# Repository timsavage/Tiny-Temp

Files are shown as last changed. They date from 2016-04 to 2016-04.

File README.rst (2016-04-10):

########
TinyTemp
########

Had all the components laying about so this is a bit of a trial project for 
making my first PCB. 

Utilises a HP QDSP-6064 bubble display, a TMP34 temperature sensor, and an 
ATTiny85, will draw very little current for a longer life.

Hardware
========

The bubble displays can be hard to come by but they do pop up on Ebay from 
time to time.

Display is driven by a pair of 74HC595 IC's, one to control segments the other 
to switch transistors to pull Cathodes to ground. As the 74HC595 can be daisy
chained on 3 pins are required to drive the display. The TMP36 uses 1 ADC 
leaving one pin free.

Note that in the schematic the 3.3 Volt regulator used is the LD33V the pin
layout differs from the 78XX series in with:
 - Pin 1: GRN
 - Pin 2: OUT
 - Pin 3: IN

The schematic uses a 78XX series symbol.

The ICSP header is optional and only really in place for convenience.

BOM
---

 - 1x HP QDSP-6064 - 7 Segment "Bubble" display
 - 1x	ATTiny 85
 - 1x	TMP34 - Temperature sensor
 - 1x LD33V - 3.3V voltage regulator
 - 2x	74HC595 - Shift register
 - 4x	2N3904 - NPN transistor
 - 5x	10k ohm resistor
 - 4x	330 ohm resistor
 - 2x	0.1uF MLC cap

Software
========

Use the install target to build, upload, and set correct fuses for an ATTiny85
using a USBTiny programmer. These settings can be tweaked in the Makefile.

All pins, voltage levels (defaults to 3.3V) can be configured in *defines.h*.

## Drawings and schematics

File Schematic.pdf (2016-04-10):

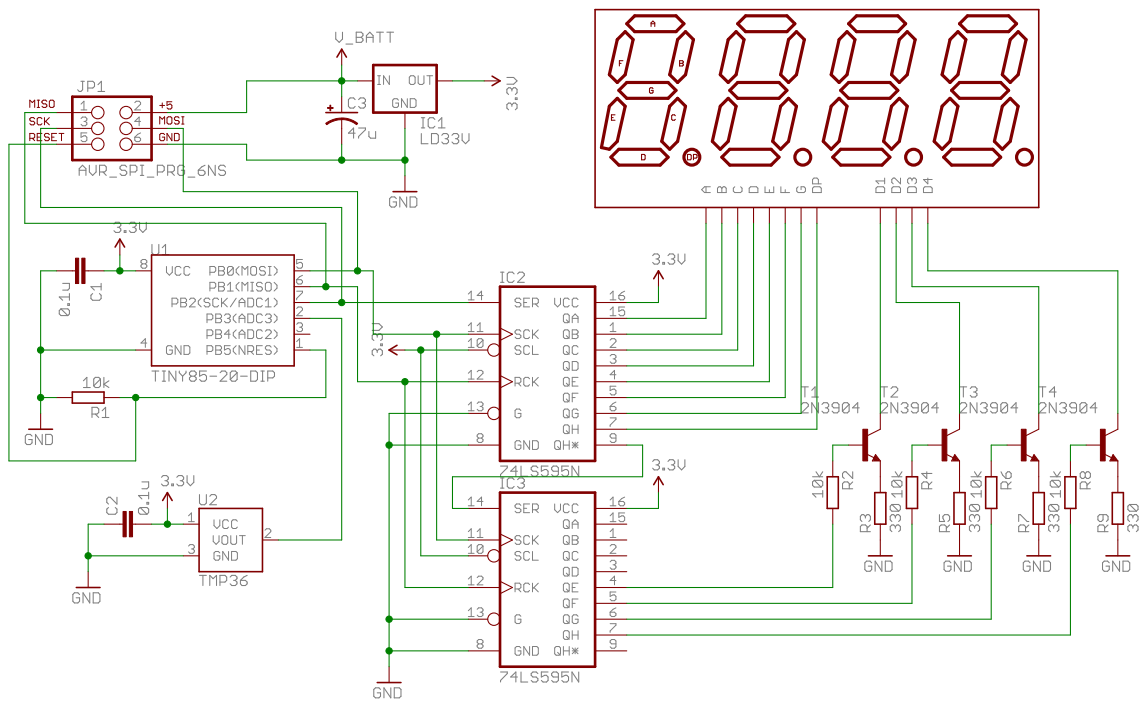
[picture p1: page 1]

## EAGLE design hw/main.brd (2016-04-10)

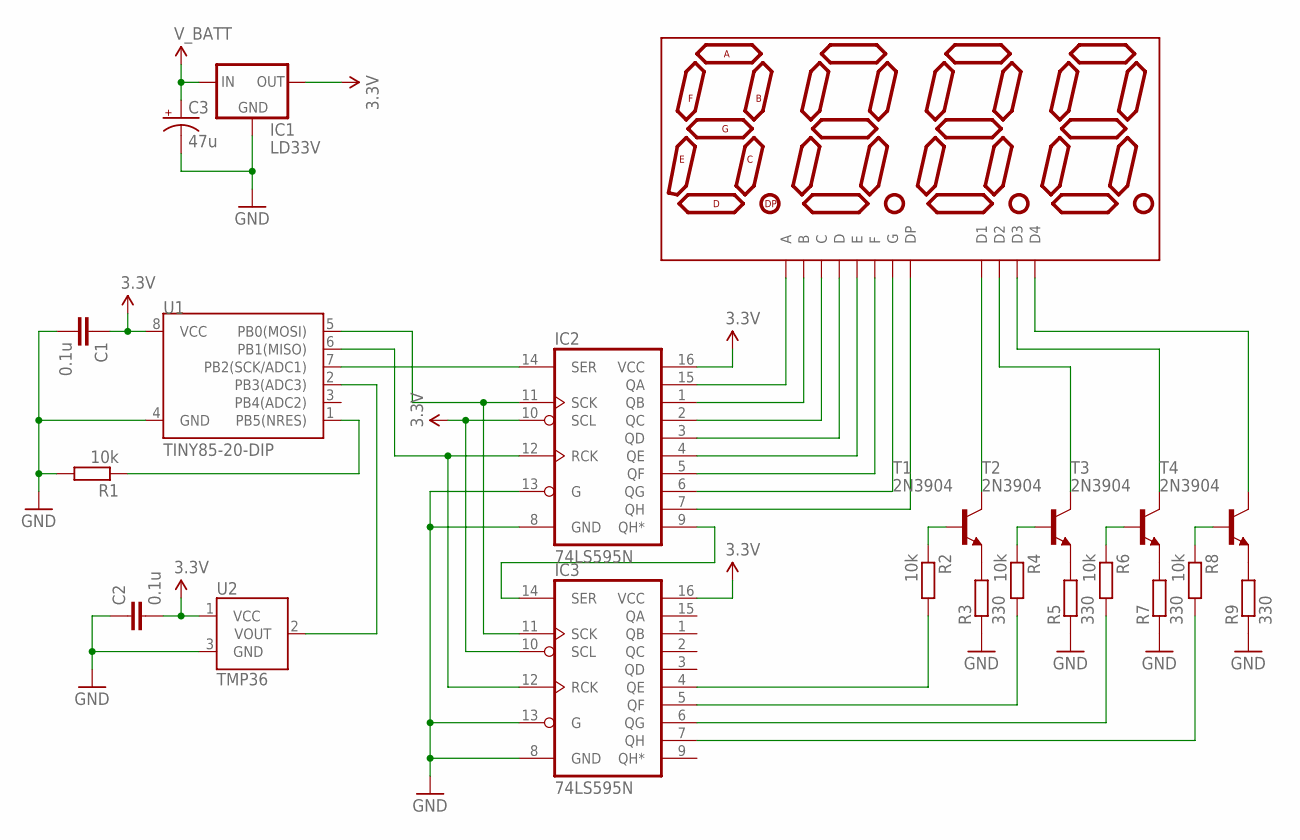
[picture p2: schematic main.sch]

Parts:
C1, C2: 0.1u; C025-025X050
C3: 47u; CPOL-RADIAL-10UF-25V
DISP1: 7-SEGMENT-4DIGIT-COUNTER-HP-BUBBLE; DIL12
IC1: LD33V; 78XXL
IC2, IC3: 74LS595N; DIL16
R1: 10k; 0204/7
R2, R4, R6, R8: 10k; 0204V
R3, R5, R7, R9: 330; 0204V
T1, T2, T3, T4: 2N3904; TO92
U1: TINY85-20-DIP; DIP08
U2: TMP36; TO-92

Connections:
GND: C1.2, C2.1, C3.2 (-), IC1.GND, IC2.8 (GND), IC2.13 (G), IC3.8 (GND), IC3.13 (G), R1.2, R3.1, R5.1, R7.1, R9.1, U1.4 (GND), U2.3 (GND); also elsewhere on the board
unnamed: DISP1.12 (A), IC2.15 (QA)
unnamed: DISP1.11 (B), IC2.1 (QB)
unnamed: DISP1.3 (C), IC2.2 (QC)
unnamed: DISP1.8 (D), IC2.3 (QD)
unnamed: DISP1.2 (E), IC2.4 (QE)
unnamed: DISP1.9 (F), IC2.5 (QF)
unnamed: DISP1.7 (G), IC2.6 (QG)
unnamed: DISP1.5 (DP), IC2.7 (QH)
unnamed: IC2.9 (QH*), IC3.14 (SER)
unnamed 10: IC2.11 (SCK), IC3.11 (SCK), U1.5 (PB0(MOSI)); also elsewhere on the board
unnamed 11: IC2.12 (RCK), IC3.12 (RCK), U1.6 (PB1(MISO)); also elsewhere on the board
unnamed: R3.2, T1.3 (E)
unnamed: R5.2, T2.3 (E)
unnamed: R9.2, T4.3 (E)
unnamed: R7.2, T3.3 (E)
unnamed: IC3.7 (QH), R8.2
unnamed: IC3.6 (QG), R6.2
unnamed: IC3.5 (QF), R4.2
unnamed: IC3.4 (QE), R2.2
unnamed: R2.1, T1.2 (B)
unnamed: R4.1, T2.2 (B)
unnamed: R6.1, T3.2 (B)
unnamed: R8.1, T4.2 (B)
unnamed: DISP1.1 (D1), T1.1 (C)
unnamed: DISP1.6 (D4), T4.1 (C)
unnamed: DISP1.4 (D3), T3.1 (C)
unnamed: DISP1.10 (D2), T2.1 (C)
unnamed: U1.2 (PB3(ADC3)), U2.2 (VOUT)
unnamed 29: R1.1, U1.1 (PB5(NRES)); also elsewhere on the board
unnamed 30: IC2.14 (SER), U1.7 (PB2(SCK/ADC1)); also elsewhere on the board
VCC: C1.1, C2.2, IC1.OUT, IC2.10 (SCL), IC2.16 (VCC), IC3.10 (SCL), IC3.16 (VCC), U1.8 (VCC), U2.1 (VCC)
V_BATT: C3.1 (+), IC1.IN; also elsewhere on the board

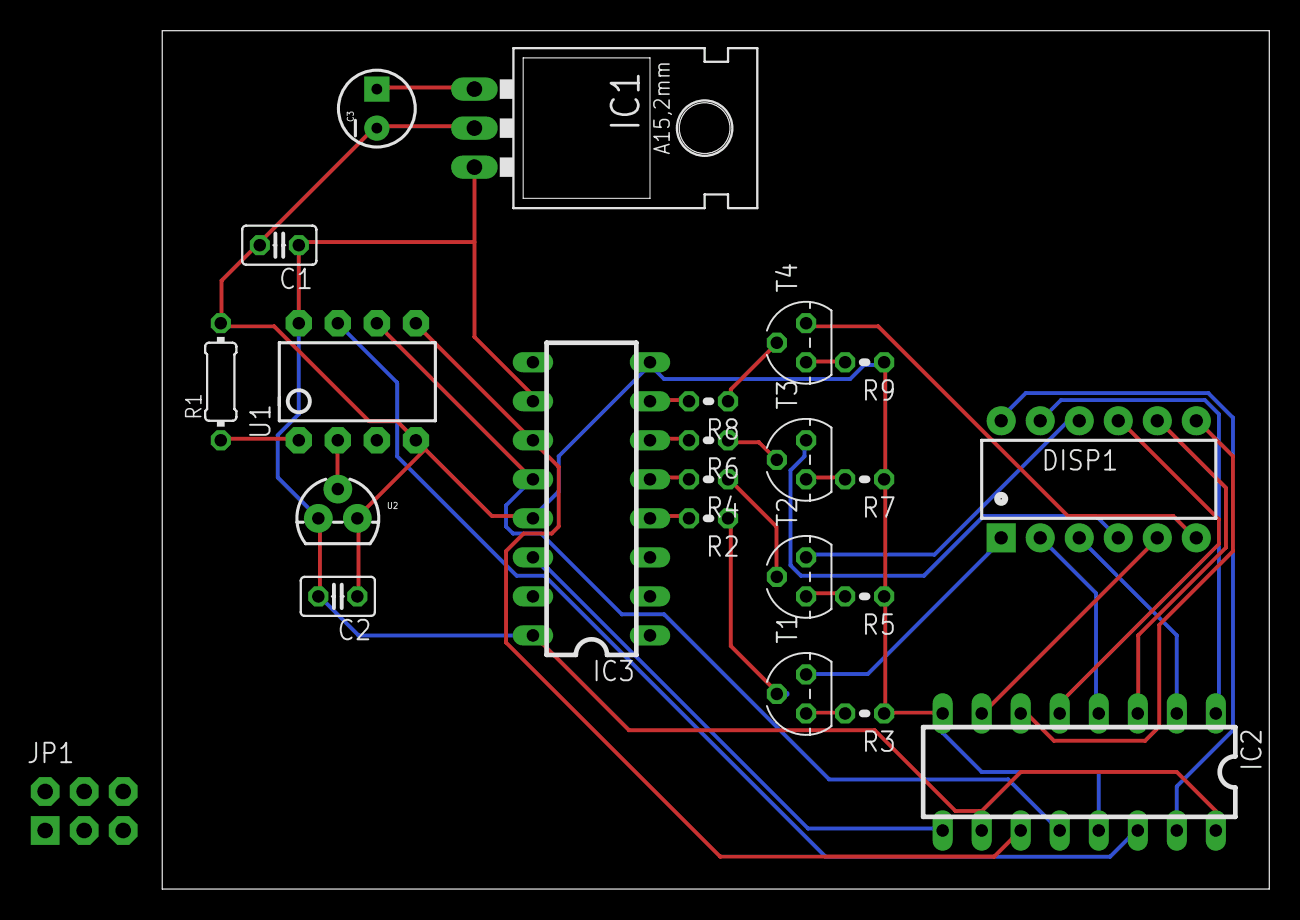
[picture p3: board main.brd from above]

Board: 2 copper layers, 72.1 x 55.9 mm, 23 parts (0 on the bottom side), 33 nets.

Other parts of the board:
JP1: AVR_SPI_PRG_6NS; 2X3-NS

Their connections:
GND: JP1.6; also elsewhere on the board
unnamed 10: JP1.4; also elsewhere on the board
unnamed 11: JP1.1; also elsewhere on the board
unnamed 29: JP1.5; also elsewhere on the board
unnamed 30: JP1.3; also elsewhere on the board
V_BATT: JP1.2; also elsewhere on the board

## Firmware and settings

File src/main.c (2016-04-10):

#include <util/delay.h>
#include <avr/interrupt.h>
#include <avr/wdt.h>

#include "defines.h"
#include "display.h"


float milliVolts = 0;
uint8_t sampleCount = 0;

void tmp34_update(void) {
  if (bit_is_clear(ADCSRA, ADSC)) {
    // Update sample buffer
    uint16_t value = ADCL | (ADCH << 8);
    milliVolts += (value * OPERATING_VOLTAGE) / 1024.0;
    sampleCount++;

    // Start next conversion
    ADCSRA |= _BV(ADSC);

    if (sampleCount >= 10) {
      milliVolts /= 10;

      // Round to 1 DP for display (offset by 10^-1)
      int16_t dispTemp = (milliVolts - 0.5) * 1000 + 0.5;

      // Generate display
      if (dispTemp < 0) display_write(CHAR_NEG);
      display_write(dispTemp / 100);
      dispTemp %= 100;
      display_write_dp(dispTemp / 10);
      display_write(dispTemp % 10);
      if (dispTemp >= 0) display_write(CHAR_SPACE);

      // Reset status
      milliVolts = 0;
      sampleCount = 0;
    }
  }
}

void tmp34_init(void) {
  // Configure ADC pre-scaler
  ADCSRA |= _BV(ADPS2) | _BV(ADPS1) | _BV(ADPS0);
  // Set mux for ADC3
  ADMUX |= 0b11;
  // Enable ADC
  ADCSRA |= _BV(ADEN);
  // Start fist conversion
  ADCSRA |= _BV(ADSC);
}

void loop(void) {
  uint8_t scaler = 0;
  while(1) {
    // Call temperature update every 16 cycles.
    if (!((scaler++) % 16)) tmp34_update();
    display_update();
  }
}

int main(void) {
  wdt_disable();

  tmp34_init();
  display_init();

  loop();
  return 1;
}

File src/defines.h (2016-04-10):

#ifndef DEFINES__H
#define DEFINES__H

#include <avr/io.h>

#define OPERATING_VOLTAGE 3.3

#define DISPLAY_CLOCK_PIN PINB0
#define DISPLAY_LATCH_PIN PINB1
#define DISPLAY_DATA_PIN  PINB2

#define TMP34_INPUT   PINB3

#endif // !DEFINES__H

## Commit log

2016-04-10 Added schematic for HW
    [main.sch]
2016-04-10 Added ICSP header
    [main.brd]
2016-04-10 Refactored temperature acquisition code to spread time across multiple cycles of the runloop. This is to reduce flicker on the display
2016-04-10 Added schematic

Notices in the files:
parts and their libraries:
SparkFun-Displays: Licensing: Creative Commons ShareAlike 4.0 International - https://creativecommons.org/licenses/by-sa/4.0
